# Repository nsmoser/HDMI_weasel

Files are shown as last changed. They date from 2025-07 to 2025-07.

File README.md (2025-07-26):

This board exists to switch between a pass-through HDMI signal and an HDMI signal generated from an RP2350A chip.
Note that this board does not contain HDMI connectors, but it does have FFC connectors for routing HDMI signals on/off board.
Has some DIP mechanical interfaces for working the chip, and an FFC connector w/ SPI & I2C pinned out for an add-on board.
Micro-SD card connector on the back to source images for the generated HDMI signal.

This was originally intended as a prank device (ex. take a screenshot of your neighbor's PC, load it on the SD card, and switch the input),
but it could also see use as a digital meeting or menu board on a single-input display where frequent switching between display on a loop and
a presentation from an external HDMI source.

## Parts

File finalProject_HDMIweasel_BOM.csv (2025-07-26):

Comment | Designator | Footprint | JLCPCB Part #
0.1u | C001,C201,C202,C203,C204,C205 | Capacitor_SMD:C_0402_1005Metric | C71629
2.2u | C101 | Capacitor_SMD:C_0402_1005Metric | C237392
47u | C102 | Capacitor_SMD:C_1210_3225Metric | C84494
4.7u | C301,C302,C303,C314 | Capacitor_SMD:C_0402_1005Metric | C71633,C77004
100n | C304,C305,C306,C307,C308,C309,C310,C311,C312,C313,C315,C318,C319 | Capacitor_SMD:C_0402_1005Metric | C71629
15p | C316,C317 | Capacitor_SMD:C_0402_1005Metric | C76950
LED | D002,D003 | LED_SMD:LED_0805_2012Metric | C7496841
LED | D001 | LED_SMD:LED_0805_2012Metric | C84260
LED | D103 | LED_SMD:LED_0805_2012Metric | C84262
ESD5Z5V0 | D101 | Diode_SMD:D_SOD-523 | C248788
PRTR5V0U2X | D102 | Package_TO_SOT_SMD:SOT-143 | C12333
ESD5Z3V3 | D301,D302,D303,D304,D305 | Diode_SMD:D_SOD-523 | C502545
Conn_01x18_Pin | J001 | Connector_FFC-FPC:Hirose_FH12-18S-0.5SH_1x18-1MP_P0.50mm_Horizontal | C506792
Conn_01x20_Pin | J201,J202 | Connector_FFC-FPC:Hirose_FH12-20S-0.5SH_1x20-1MP_P0.50mm_Horizontal | C596730
Micro_SD_Card | J301 | Connector_Card:microSD_HC_Hirose_DM3AT-SF-PEJM5 | C114218
1u | L101 | Inductor_SMD:L_Sunlord_SWPA4030S | C42193
3.3u | L301 | Inductor_SMD:L_Sunlord_SWPA3015S | C48020
USB_C_Plug_USB2.0 | P101 | Connector_USB:USB_C_Receptacle_HRO_TYPE-C-31-M-12 | C165948
BSS138 | Q001,Q002,Q003,Q201 | Package_TO_SOT_SMD:SOT-23 | C24553
BSS83P | Q101 | Package_TO_SOT_SMD:SOT-23 | C2932927
100k | R001,R003,R005,R102,R103,R204,R309,R310 | Resistor_SMD:R_0402_1005Metric | C481918
22 | R002 | Resistor_SMD:R_0805_2012Metric | C17561
42.2 | R004,R006 | Resistor_SMD:R_0805_2012Metric | C410018
453k | R101 | Resistor_SMD:R_0402_1005Metric | C843903
188 | R104 | Resistor_SMD:R_0805_2012Metric | C104054
10k | R201,R202,R203,R305,R306,R311 | Resistor_SMD:R_0402_1005Metric | C71617
27 | R301,R302 | Resistor_SMD:R_0402_1005Metric | C138021
1k | R303,R304 | Resistor_SMD:R_0402_1005Metric | C163485
100K | R307,R308 | Resistor_SMD:R_0402_1005Metric | C481918
33 | R312 | Resistor_SMD:R_0402_1005Metric | C25105
SW_DIP_x01 | SW301,SW302,SW304,SW305 | Button_Switch_SMD:SW_DIP_SPSTx01_Slide_6.7x4.1mm_W6.73mm_P2.54mm_LowProfile_JPin | C2884835
TS5A3159ADCK | U001,U206 | Package_TO_SOT_SMD:SOT-363_SC-70-6 | C475493
TPS62A02ADRL | U101 | Package_TO_SOT_SMD:SOT-563 | C5820994
TMUXHS4412 | U201 | Package_DFN_QFN:WQFN-42-1EP_3.5x9mm_P0.5mm_EP2.05x7.55mm_ThermalVias | C3657223
TPD4E02B04DQA | U202,U203,U204,U205,U304 | Package_SON:USON-10_2.5x1.0mm_P0.5mm | C106794
RP2350 | U301 | Package_DFN_QFN:QFN-60-1EP_7x7mm_P0.4mm_EP3.4x3.4mm_ThermalVias | C42411118
W25Q128JVP | U302 | Package_SON:WSON-8-1EP_6x5mm_P1.27mm_EP3.4x4.3mm | C190862
TXS0102DCT | U303 | Package_SO:SSOP-8_2.95x2.8mm_P0.65mm | C324082
ABM8-22272-T3 | Y1 | Crystal:Crystal_SMD_3225-4Pin_3.2x2.5mm | C20625731

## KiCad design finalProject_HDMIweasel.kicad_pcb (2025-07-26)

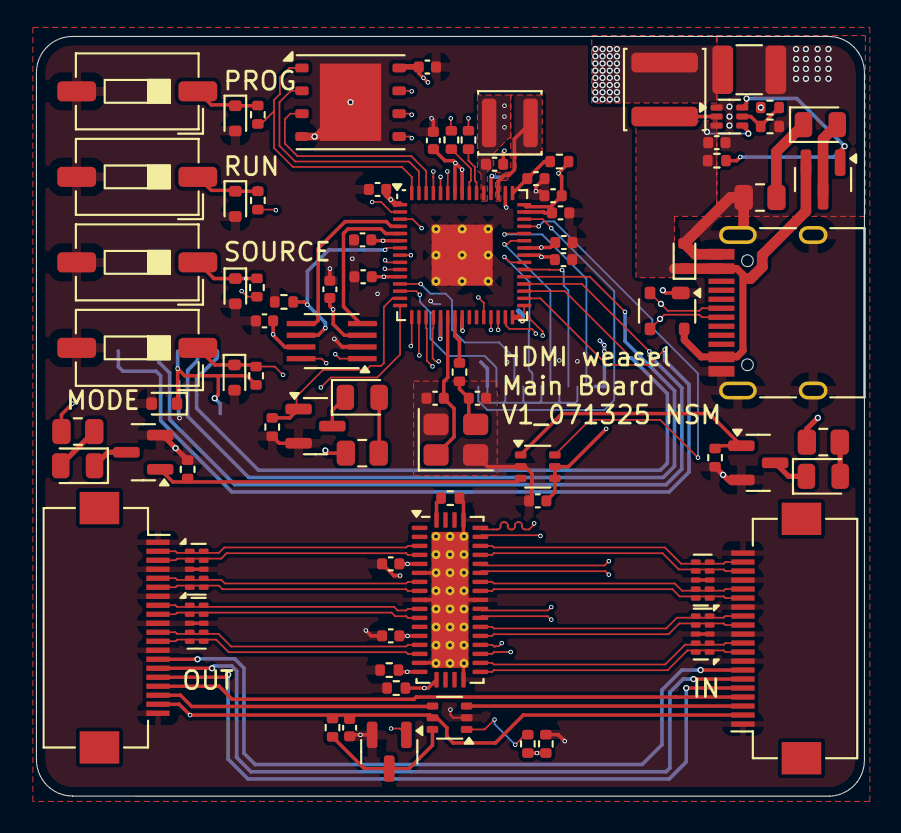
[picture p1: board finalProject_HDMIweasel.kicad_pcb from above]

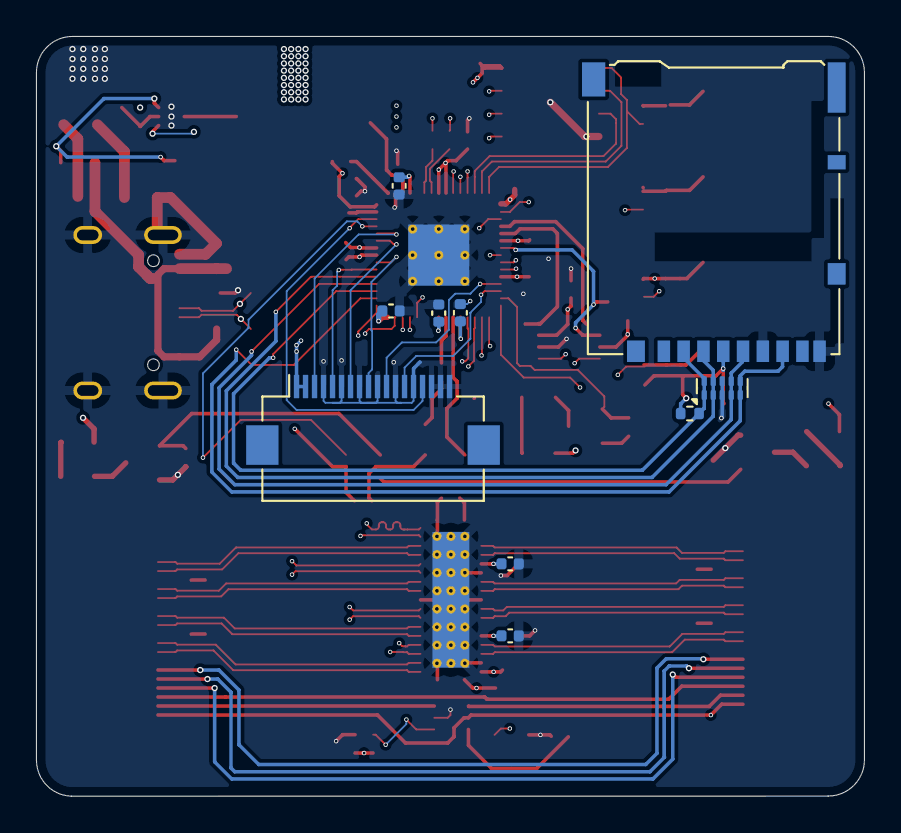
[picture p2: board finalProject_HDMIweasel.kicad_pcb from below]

Board: 6 copper layers, 46.0 x 42.2 mm, 93 parts (10 on the bottom side), 90 nets.

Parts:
C001, C201, C202, C203, C204, C205: 0.1u; C_0402_1005Metric
C101: 2.2u; C_0402_1005Metric
C102: 47u; C_1210_3225Metric
C301, C302, C303, C314: 4.7u; C_0402_1005Metric
C304, C305, C306, C307, C308, C309, C310, C311, C312, C313, C315, C318, C319: 100n; C_0402_1005Metric
C316, C317: 15p; C_0402_1005Metric
D001, D002, D003, D103: LED; LED_0805_2012Metric
D101: ESD5Z5V0; D_SOD-523
D102: PRTR5V0U2X; SOT-143
D301, D302, D303, D304, D305: ESD5Z3V3; D_SOD-523
J001: Conn_01x18_Pin; Hirose_FH12-18S-0.5SH_1x18-1MP_P0.50mm_Horizontal
J201, J202: Conn_01x20_Pin; Hirose_FH12-20S-0.5SH_1x20-1MP_P0.50mm_Horizontal
J301: Micro_SD_Card; microSD_HC_Hirose_DM3AT-SF-PEJM5
L101: 1u; L_Sunlord_SWPA4030S
L301: 3.3u; L_Sunlord_SWPA3015S
P101: USB_C_Plug_USB2.0; USB_C_Receptacle_HRO_TYPE-C-31-M-12
Q001, Q002, Q003, Q201: BSS138; SOT-23
Q101: BSS83P; SOT-23
R001, R003, R005, R102, R103, R204, R309, R310: 100k; R_0402_1005Metric
R002: 22; R_0805_2012Metric
R004, R006: 42.2; R_0805_2012Metric
R101: 453k; R_0402_1005Metric
R104: 188; R_0805_2012Metric
R201, R202, R203, R305, R306, R311: 10k; R_0402_1005Metric
R301, R302: 27; R_0402_1005Metric
R303, R304: 1k; R_0402_1005Metric
R307, R308: 100K; R_0402_1005Metric
R312: 33; R_0402_1005Metric
SW301, SW302, SW304, SW305: SW_DIP_x01; SW_DIP_SPSTx01_Slide_6.7x4.1mm_W6.73mm_P2.54mm_LowProfile_J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
U001, U206: TS5A3159ADCK; SOT-363_SC-70-6
U101: TPS62A02ADRL; SOT-563
U201: TMUXHS4412; WQFN-42-1EP_3.5x9mm_P0.5mm_EP2.05x7.55mm_ThermalVias
U202, U203, U204, U205, U304: TPD4E02B04DQA; USON-10_2.5x1.0mm_P0.5mm
U301: RP2350; QFN-60-1EP_7x7mm_P0.4mm_EP3.4x3.4mm_ThermalVias
U302: W25Q128JVP; WSON-8-1EP_6x5mm_P1.27mm_EP3.4x4.3mm
U303: TXS0102DCT; SSOP-8_2.95x2.8mm_P0.65mm
Y1: ABM8-22272-T3; Crystal_SMD_3225-4Pin_3.2x2.5mm

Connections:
+1V1: C302.1, C312.1, C313.1, C314.1, L301.1, U301.6 (DVDD), U301.23 (DVDD), U301.39 (DVDD), U301.50 (VREG_FB)
+3.3V: C001.1, C102.1, C201.1, C202.1, C203.1, C204.1, C303.1, C304.1, C305.1, C306.1, C307.1, C308.1, C309.1, C310.1, C311.1, C315.1, C319.1, D305.1 (K), J001.1, J001.2, J301.4 (VDD), L101.2, R002.1, R004.1, R006.1, R101.1, R309.1, R310.1, R311.2, R312.2, U001.4, U001.5 (V+), U201.5 (VCC), U201.13 (VCC), U301.1 (IOVDD), U301.11 (IOVDD), U301.20 (IOVDD), U301.30 (IOVDD), U301.38 (IOVDD), U301.44 (ADC_AVDD), U301.45 (IOVDD), U301.49 (VREG_VIN), U301.53 (USB_OTP_VDD), U301.54 (QSPI_IOVDD), U302.8 (VCC), U303.3 (VCCA)
/HDMI_switch/CEC: J201.14, J202.7, U301.15 (GPIO11)
/HDMI_switch/HDMI_IN_CK+: J202.19, U201.36 (DB0P), U205.5 (IO4)
/HDMI_switch/HDMI_IN_CK-: J202.18, U201.35 (DB0N), U205.4 (IO3)
/HDMI_switch/HDMI_IN_D0+: J202.16, U201.32 (DB1P), U205.2 (IO2)
/HDMI_switch/HDMI_IN_D0-: J202.15, U201.31 (DB1N), U205.1 (IO1)
/HDMI_switch/HDMI_IN_D1+: J202.13, U201.27 (DB2P), U204.5 (IO4)
/HDMI_switch/HDMI_IN_D1-: J202.12, U201.26 (DB2N), U204.4 (IO3)
/HDMI_switch/HDMI_IN_D2+: J202.10, U201.23 (DB3P), U204.2 (IO2)
/HDMI_switch/HDMI_IN_D2-: J202.9, U201.22 (DB3N), U204.1 (IO1)
/HDMI_switch/HDMI_OUT_CLK+: J201.2, U201.3 (D0P), U203.1 (IO1)
/HDMI_switch/HDMI_OUT_CLK-: J201.3, U201.4 (D0N), U203.2 (IO2)
/HDMI_switch/HDMI_OUT_D0+: J201.5, U201.7 (D1P), U203.4 (IO3)
/HDMI_switch/HDMI_OUT_D0-: J201.6, U201.8 (D1N), U203.5 (IO4)
/HDMI_switch/HDMI_OUT_D1+: J201.8, U201.10 (D2P), U202.1 (IO1)
/HDMI_switch/HDMI_OUT_D1-: J201.9, U201.11 (D2N), U202.2 (IO2)
/HDMI_switch/HDMI_OUT_D2+: J201.11, U201.14 (D3P), U202.4 (IO3)
/HDMI_switch/HDMI_OUT_D2-: J201.12, U201.15 (D3N), U202.5 (IO4)
/HDMI_switch/HOTPLUG_OUT: J201.18, U206.4
/HDMI_switch/PD: R201.1, U201.18 (PD), U301.3 (GPIO1)
/HDMI_switch/RPI_CLK+: U201.38 (DA0P), U301.18 (GPIO14)
/HDMI_switch/RPI_CLK-: U201.37 (DA0N), U301.19 (GPIO15)
/HDMI_switch/RPI_D0+: U201.34 (DA1P), U301.29 (GPIO18)
/HDMI_switch/RPI_D0-: U201.33 (DA1N), U301.31 (GPIO19)
/HDMI_switch/RPI_D1+: U201.29 (DA2P), U301.27 (GPIO16)
/HDMI_switch/RPI_D1-: U201.28 (DA2N), U301.28 (GPIO17)
/HDMI_switch/RPI_D2+: U201.25 (DA3P), U301.16 (GPIO12)
/HDMI_switch/RPI_D2-: U201.24 (DA3N), U301.17 (GPIO13)
/HDMI_switch/RPI_HOTPLUG: R307.2, U206.1
/HDMI_switch/SCL: J201.15, J202.6, U303.1 (B2)
/HDMI_switch/SDA: J201.16, J202.5, U303.8 (B1)
/HDMI_switch/SEL: Q201.1 (G), R202.1, U201.17 (SEL), U301.2 (GPIO0)
/HDMI_switch/V_HDMI: C205.1, C318.1, J201.19, J202.2, R204.1, U206.5 (V+), U303.7 (VCCB)
/HDMI_switch/hotplug: J202.3, U206.3
/HDMI_switch/util: J201.17, J202.4
/Microcontroller/HDMI_COMM_EN: R306.2, U301.7 (GPIO4), U303.6 (OE)
/Microcontroller/LED_HDMISOURCE: U001.6, U301.42 (GPIO28_ADC2)
/Microcontroller/LED_SYSACTIVE: Q001.1 (G), R001.1, U301.14 (GPIO10)
/Microcontroller/MANUAL_SWITCH: D303.1 (K), R309.2, SW304.1, U301.9 (GPIO6)
/Microcontroller/MODE_SWITCH: D304.1 (K), R310.2, SW305.1, U301.10 (GPIO7)
/Microcontroller/QSPI_SS: R303.2, U301.60 (QSPI_SS), U302.1 (~CS)
/Microcontroller/RPI_ADC (GPIO29): J001.15, U301.43 (GPIO29_ADC3)
/Microcontroller/RPI_SCL0 (GPIO9): J001.13, U301.13 (GPIO9)
/Microcontroller/RPI_SCL1: U301.5 (GPIO3), U303.4 (A2)
/Microcontroller/RPI_SDA0 (GPIO8): J001.11, U301.12 (GPIO8)
/Microcontroller/RPI_SDA1: U301.4 (GPIO2), U303.5 (A1)
/Microcontroller/RPI_SPI1_CS0 (GPIO25): J001.9, U301.37 (GPIO25)
/Microcontroller/RPI_SPI1_RX (GPIO24): J001.5, U301.36 (GPIO24)
/Microcontroller/RPI_SPI1_SCK (GPIO26): J001.7, U301.40 (GPIO26_ADC0)
/Microcontroller/RPI_SPI1_TX (GPIO27): J001.3, U301.41 (GPIO27_ADC1)
/Microcontroller/SPI0_CS0: J301.2 (DAT3/CD), R311.1, U301.33 (GPIO21), U304.1 (IO1)
/Microcontroller/SPI0_RX: J301.7 (DAT0), U301.32 (GPIO20), U304.5 (IO4)
/Microcontroller/SPI0_SCK: J301.5 (CLK), U301.34 (GPIO22), U304.4 (IO3)
/Microcontroller/SPI0_TX: J301.3 (CMD), U301.35 (GPIO23), U304.2 (IO2)
/Microcontroller/USB_D1N: R301.1, U301.51 (USB_DN)
/Microcontroller/USB_D1P: R302.1, U301.52 (USB_DP)
/Microcontroller/USB_DN: D102.2 (I/O1), P101.A7 (D-), R301.2
/Microcontroller/USB_DP: D102.3 (I/O2), P101.A6 (D+), R302.2
/Microcontroller/VREG_LX: L301.2, U301.48 (VREG_LX)
GND: C001.2, C101.2, C102.2, C201.2, C202.2, C203.2, C204.2, C205.2, C301.2, C302.2, C303.2, C304.2, C305.2, C306.2, C307.2, C308.2, C309.2, C310.2, C311.2, C312.2, C313.2, C314.2, C315.2, C316.2, C317.2, C318.2, C319.2, D101.2 (A), D102.1 (GND), D301.2 (A), D302.2 (A), D303.2 (A), D304.2 (A), D305.2 (A), J001.4, J001.6, J001.8, J001.10, J001.12, J001.14, J001.16, J001.17, J001.18, J201.1, J201.4, J201.7, J201.10, J201.13, J201.20, J202.1, J202.8, J202.11, J202.14, J202.17, J202.20, J301.6 (VSS), J301.9 (SHIELD), P101.A1 (GND), P101.A12 (GND), P101.B1 (GND), P101.B12 (GND), P101.S1 (SHIELD), Q001.2 (S), Q002.2 (S), Q003.2 (S), Q201.2 (S), R001.2, R003.2, R005.2, R102.2, R104.2, R201.2, R202.2, R203.1, R306.1, R308.2, SW301.2, SW302.2, SW304.2, SW305.2, U001.2 (GND), U101.1 (GND), U201.6 (GND), U201.9 (GND), U201.16 (GND), U201.21 (GND), U201.30 (GND), U201.39 (GND), U201.43 (GND), U202.3 (G), U202.8 (G), U203.3 (G), U203.8 (G), U204.3 (G), U204.8 (G), U205.3 (G), U205.8 (G), U206.2 (GND), U301.47 (VREG_PGND), U301.61 (GND), U302.4 (GND), U302.9 (EP), U303.2 (GND), U304.3 (G), U304.8 (G), Y1.2, Y1.4
unnamed: C316.1, R304.1, Y1.3
unnamed: D001.2 (A), R002.2
unnamed: D001.1 (K), Q001.3 (D)
unnamed: D002.2 (A), R004.2
unnamed: D002.1 (K), Q002.3 (D)
unnamed: D003.2 (A), R006.2
unnamed: D003.1 (K), Q003.3 (D)
unnamed: D103.2 (A), Q101.3 (D)
unnamed: D103.1 (K), R104.1
unnamed: D301.1 (K), R303.1, SW301.1
unnamed: D302.1 (K), R305.1, SW302.1
unnamed: Q002.1 (G), R003.1, U001.3
unnamed: Q003.1 (G), R005.1, U001.1
unnamed: Q101.1 (G), R103.2, U101.6 (PG)
unnamed: Q201.3 (D), R204.2, U206.6
unnamed: R101.2, R102.1, U101.5 (FB)
unnamed: L101.1, U101.2 (SW)
unnamed: R203.2, U201.42 (RSVD)
unnamed: R307.1, R308.1, U301.8 (GPIO5)
unnamed: U301.56 (QSPI_SCLK), U302.6 (CLK)
unnamed: U301.57 (QSPI_SD0), U302.5 (DI/IO_{0})
unnamed: U301.59 (QSPI_SD1), U302.2 (DO/IO_{1})
unnamed: U301.58 (QSPI_SD2), U302.3 (~WP/IO_{2})
unnamed: U301.55 (QSPI_SD3), U302.7 (~HOLD/~RESET/IO_{3})
unnamed: R305.2, U301.26 (RUN)
unnamed: C301.1, R312.1, U301.46 (VREG_AVDD)
unnamed: C317.1, U301.21 (XIN), Y1.1
unnamed: R304.2, U301.22 (XOUT)
VBUS: C101.1, D101.1 (K), D102.4 (VCC), P101.A4 (VBUS), P101.A9 (VBUS), P101.B4 (VBUS), P101.B9 (VBUS), Q101.2 (S), R103.1, U101.3 (VIN), U101.4 (EN)
